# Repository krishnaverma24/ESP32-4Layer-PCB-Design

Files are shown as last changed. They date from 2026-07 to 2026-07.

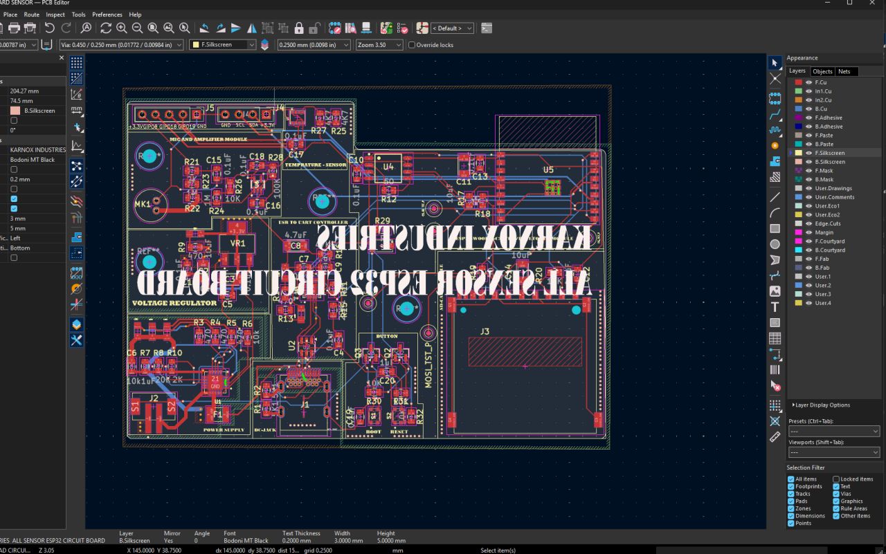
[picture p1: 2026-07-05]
1781695710935.jpg

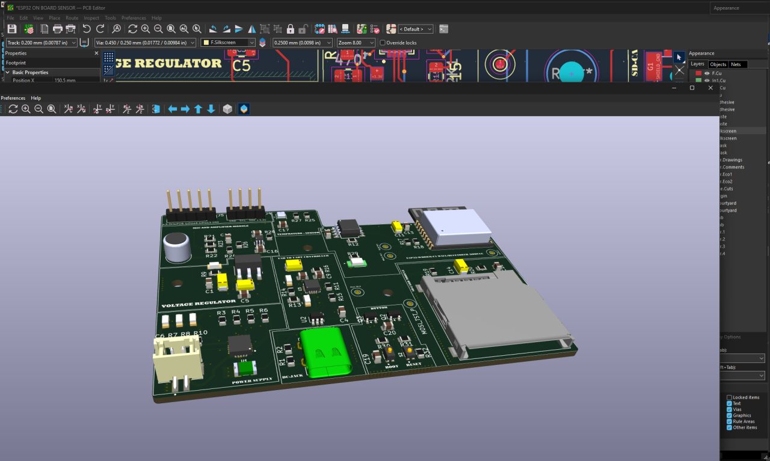
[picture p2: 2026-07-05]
1781695710932.jpg

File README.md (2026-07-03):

# ESP32 All-Sensor Board (4-Layer PCB Design)

## 📖 Overview
This repository contains the design files for a custom 4-layer PCB integrating the ESP32 microcontroller with multiple sensors and supporting circuits.  
The board is designed as a compact all-in-one sensor platform for IoT and embedded system experiments. It includes sensor interfaces, amplifier circuits, and a regulated power section, making it suitable for real-world prototyping and academic projects.

---

## ⚙️ Features
- **ESP32 Microcontroller**
  - Dual-core processor with Wi-Fi + Bluetooth
  - GPIO breakout pins for external modules
- **Integrated Sensors**
  - BMP90 sensor for pressure and temperature measurement
  - Humidity sensor interface for environmental monitoring
- **Amplifier System**
  - Signal conditioning stage for sensor outputs
  - Designed for clean analog-to-digital conversion
- **Power Section**
  - LDO-based regulation for 3.3V and 5V rails
  - Separate copper planes for power and ground
  - Decoupling capacitors for noise reduction
- **PCB Design**
  - 4-layer stack-up for optimized routing
  - Dedicated copper planes for stability
  - Compact layout with clear separation of analog and digital sections

---

## 📂 Repository Contents
- **/schematics** → Circuit schematic files (`.sch`, `.pdf`)
- **/pcb_layout** → PCB design files (`.kicad_pcb`, EasyEDA exports)
- **/gerber** → Gerber files for fabrication
- **/images** → PCB screenshots (top layer, bottom layer, 3D view)
- **README.md** → Project description and usage details

---

## 🖼️ PCB Views
Top Layer
Bottom Layer
3D View

---

## 🚀 Tools Used
- **EasyEDA** → schematic & PCB design
- **KiCad** → verification and cross-checking
- **Standard PCB workflow** → Gerber export for manufacturing

---

## 🎯 Applications
- IoT sensor fusion projects
- Environmental monitoring (temperature, humidity, pressure)
- Embedded system prototyping with ESP32
- Signal conditioning experiments with amplifier circuits
- Academic learning for PCB design and hardware integration

---

## 🛠 How to Use
1. Clone this repository  
2. Open schematic files in EasyEDA/KiCad  
3. Review PCB layout and modify if needed  
4. Use Gerber files for fabrication  
5. Assemble components and test sensor outputs with ESP32 firmware  

---

## 📌 Future Improvements
- Add more sensors (gas, accelerometer, gyroscope)  
- Improve amplifier stage for higher accuracy  
- Add USB-C power input and charging circuit  
- Integrate OLED display for real-time sensor data  

---

## 📜 License
This project is licensed under the **MIT License** – feel free to use, modify, and share with proper credit.

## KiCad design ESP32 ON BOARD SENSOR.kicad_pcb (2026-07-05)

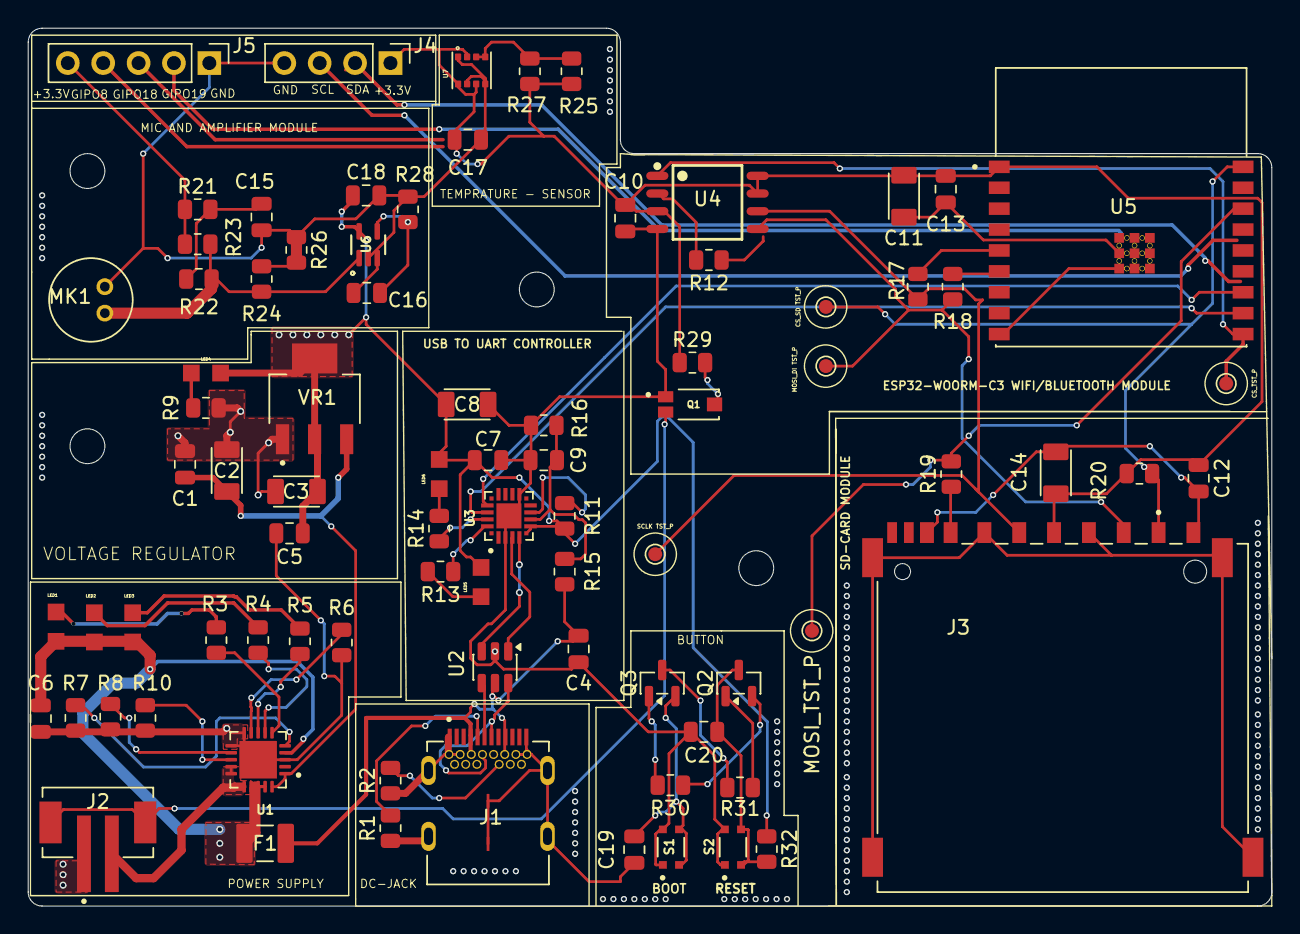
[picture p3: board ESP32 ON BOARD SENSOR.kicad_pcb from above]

Board: 4 copper layers, 89.2 x 63.0 mm, 83 parts (0 on the bottom side), 52 nets.

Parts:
C1: 0,1uF; C_0805_2012Metric
C2, C3, C13, C14: 10uF; RESC3216X125N
C4, C5, C7, C10, C11, C12, C15, C16, C17, C18, C19: 0.1uF; C_0805_2012Metric
C6, C9, C20: 1uF; C_0805_2012Metric
C8: 4.7uF; RESC3216X125N
CS_TST_P: Test CS; TestPoint_Pad_D1.0mm
F1: 0ZCH0110AF2E; FUSC3225X100N
J1: SS-52400-003; BELFUSE_SS-52400-003
J2: B2B-PH-SM4-TB; JST_B2B-PH-SM4-TB
J3: GSD090012SEU; AMPHENOL_GSD090012SEU
J4: Conn_01x04_Pin; PinHeader_1x04_P2.54mm_Vertical
J5: Conn_01x05_Pin; PinHeader_1x05_P2.54mm_Vertical
LED1, LED2, LED3, LED4, LED5, LED6: LTST-C170KRKT; DIOC200X125X110
MK1: CMC-5042PF-AC; CUI_CMC-5042PF-AC
MOSI_TST_P: Test MOSI_DO; TestPoint_Pad_D1.0mm
Q1: TEMT6000X01; TRANS_TEMT6000X01
Q2, Q3: BC817; SOT-23
R1, R2: 5K1; R_0805_2012Metric
R3, R4, R5, R9, R13, R14: 470; R_0805_2012Metric
R6, R7: 10k; R_0805_2012Metric
R8: 20K; R_0805_2012Metric
R10, R21, R22: 2K; R_0805_2012Metric
R11: 1K; R_0805_2012Metric
R12, R17, R18, R19: 50; R_0805_2012Metric
R15: 22K1; R_0805_2012Metric
R16: 47K5; R_0805_2012Metric
R20, R26, R30, R31, R32: 10K; R_0805_2012Metric
R23, R24: 1M; R_0805_2012Metric
R25, R27: 4K7; R_0805_2012Metric
R28: 100K; R_0805_2012Metric
R29: R; R_0805_2012Metric
S1: BOOT; SW_USLPT2819DT2TR
S2: RESET; SW_USLPT2819DT2TR
TP1: Test MOSI_DI; TestPoint_Pad_D1.0mm
TP3: Test SCLK; TestPoint_Pad_D1.0mm
TP4: Test CS_SD; TestPoint_Pad_D1.0mm
U1: MCP73871-2CAI_ML; QFN50P400X400X100-21N
U2: USBLC6-2SC6; SOT-23-6
U3: CP2102N-A02-GQFN20R; SILABS_CP2102N-A02-GQFN20R
U4: W25Q32JVSSIQ; SOIC127P790X216-8N
U5: ESP32-C3-WROOM-02-H4; MODULE_ESP32-C3-WROOM-02-H4
U6: MAX4466EXK; SOT65P210X110-5N
U7: BME280; PSON65P250X250X100-8N
VR1: LM1117MPX-3.3; VREG_LM1117MPX-3.3

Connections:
+3.3V: C3.1, C5.1, C7.1, C8.2, C10.1, C11.1, C12.1, C13.1, C14.1, C17.1, C18.1, J3.4 (VDD1), J4.1, J5.5, LED4.+, LED5.+, LED6.+, R11.1, R20.1, R21.1, R23.1, R25.1, R27.1, R29.1, R32.1, U3.6 (VDD), U3.7 (VREGIN), U4.3 (~WP(IO2)), U4.7 (~HOLD/~RESET(IO3)), U4.8 (VCC), U5.1 (3V3), U6.5 (VCC), U7.2 (CSB), U7.6 (VDDIO), U7.8 (VDD), VR1.2 (VOUT_2), VR1.4 (VOUT_4)
+5V: C1.1, C2.1, U1.1 (OUT), U1.20 (OUT), VR1.3 (VIN)
/+5V_USB: C6.2, F1.1, LED1.+, LED2.+, LED3.+, U1.2 (VPCC), U1.4 (PROG2), U1.17 (CE), U1.18 (IN), U1.19 (IN)
/CHARGED: R5.1, U1.8 (STAT1/~LBO)
/CHARGING: LED1.-, R3.2
/CHARGING_POWER_GOOD: R4.1, U1.7 (STAT2)
/ESP32-C3-02/CD_SD: J3.1 (CD/DAT3), R20.2, TP4.1 (1_1), U5.18 (IO0)
/ESP32-C3-02/CS: CS_TST_P.1 (1_1), U4.1 (~CS), U5.10 (IO10)
/ESP32-C3-02/MISO_DO: MOSI_TST_P.1 (1_1), R19.2, U5.16 (IO2)
/ESP32-C3-02/MOSI_DI: J3.2 (CMD), R18.2, TP1.1 (1_1), U4.5 (DI(IO0))
/ESP32-C3-02/RX_TX: U3.17 (RXD), U5.12 (TXD)
/ESP32-C3-02/SCLK: J3.5 (CLK), R17.1, TP3.1 (1_1), U4.6 (CLK)
/ESP32-C3-02/SENSORS/MIC_OUT: C16.2, R28.2, U6.4 (OUT)
/ESP32-C3-02/SENSORS/PHOTO_C: Q1.3, R29.2
/ESP32-C3-02/SENSORS/SCL: R25.2, R27.2, U7.3 (SDI), U7.4 (SCK)
/ESP32-C3-02/TX_RX: U3.18 (TXD), U5.11 (RXD)
/ESP32-C3-02/USB_D+: U2.3 (I/O2), U3.5 (D-)
/ESP32-C3-02/USB_D-: U2.1 (I/O1), U3.4 (D+)
/ESP32-C3-02/USER_INTERFACE/BOOT: C19.1, Q3.2 (E), S1.3, S1.4
/ESP32-C3-02/USER_INTERFACE/DTR: Q3.3 (C), R31.1
/ESP32-C3-02/USER_INTERFACE/EN: C20.1, Q2.3 (C), R32.2, S2.3, S2.4
/ESP32-C3-02/USER_INTERFACE/RTS: Q2.2 (E), R30.1
/USB_DN: J1.A7 (DN1), J1.B7 (DN2), U2.6 (I/O1)
/USB_DP: J1.A6 (DP1), J1.B6 (DP2), U2.4 (I/O2)
/VBAT: J2.2, U1.14 (VBAT), U1.15 (VBAT), U1.16 (VBAT_SENSE)
/VBUS: C4.1, F1.2, J1.A4 (VBUSA1), J1.A9 (VBUSA2), J1.B4 (VBUSB1), J1.B9 (VBUSB2), R15.1, U2.5 (VBUS)
GND: C1.2, C2.2, C3.2, C4.2, C5.2, C6.1, C7.2, C8.1, C9.2, C10.2, C11.2, C12.2, C13.2, C14.2, C15.1, C16.1, C17.2, C18.2, C19.2, C20.2, J1.A1 (GNDA1), J1.A12 (GNDA2), J1.B1 (GNDB1), J1.B12 (GNDB2), J1.G1 (GND/SHIELD), J1.G2 (GND/SHIELD), J1.G3 (GND/SHIELD), J1.G4 (GND/SHIELD), J1.S1 (GND/SHIELD), J1.S2 (GND/SHIELD), J1.S3 (GND/SHIELD), J1.S4 (GND/SHIELD), J2.1, J3.8 (DAT1), J3.9 (DAT2), J4.4, J5.1, MK1.GND, Q1.1, R1.1, R2.1, R6.1, R7.2, R8.2, R9.2, R10.2, R16.2, R24.2, R26.1, R26.2, R28.1, S1.1, S1.2, S2.1, S2.2, U1.3 (SEL), U1.10 (VSS), U1.11 (VSS), U1.21 (VSS), U2.2 (GND), U3.3 (GND), U3.12 (GND), U3.21 (GND), U4.4 (GND), U5.9 (GND), U5.19 (GND), U5.20 (GND), U5.21 (GND), U5.22 (GND), U5.23 (GND), U5.24 (GND), U5.25 (GND), U5.26 (GND), U5.27 (GND), U5.28 (GND), U5.29 (GND), U5.30 (GND), U5.31 (GND), U5.32 (GND), U5.33 (GND), U5.34 (GND), U5.35 (GND), U5.36 (GND), U5.37 (GND), U5.38 (GND), U5.39 (GND), U6.2 (GND), U6.3 (IN-), U7.1 (GND), U7.5 (SDO), U7.7 (GND), VR1.1 (GND)
unnamed: C15.2, R21.2, R22.1
unnamed: J1.A5 (CC1), R1.2
unnamed: J1.B5 (CC2), R2.2
unnamed: J3.7 (DAT0), R19.1
unnamed: LED2.-, R4.2
unnamed: LED3.-, R5.2
unnamed: LED4.-, R9.1
unnamed: LED5.-, R13.2
unnamed: LED6.-, R14.2
unnamed: Q2.1 (B), R31.2
unnamed: Q3.1 (B), R30.2
unnamed: R10.1, U1.13 (PROG1)
unnamed: R8.1, U1.12 (PROG3)
unnamed: R7.1, U1.5 (THERM)
unnamed: R3.1, U1.6 (~PG)
unnamed: R6.2, U1.9 (~TE)
unnamed: R13.1, U3.20 (GPIO.2/TXT)
unnamed: R14.1, U3.19 (GPIO.3/RXT)
unnamed: C9.1, R15.2, R16.1, U3.8 (VBUS)
unnamed: R11.2, U3.9 (~RST)
unnamed: R12.2, U4.2 (DO(IO1))
unnamed: R17.2, U5.5 (IO6)
unnamed: R18.1, U5.6 (IO7)
unnamed: MK1.OUT, R22.2, R23.2, R24.1, U6.1 (IN+)
SHIELD_GND: J3.3 (VSS1), J3.6 (VSS2), J3.G1 (SHIELD_GND), J3.G2 (SHIELD_GND), J3.G3 (SHIELD_GND), J3.G4 (SHIELD_GND)

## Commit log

2026-07-05 esp 32 schematic
    [ESP32 ON BOARD SENSOR.kicad_pcb, ESP32 ON BOARD SENSOR.kicad_sch, ESP32-C3-02.kicad_sch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]
2026-07-05 PCB SCHEAMTICS OR 3 D-VIEW OF PCB
    HERE I UPLOAD SOME JPG IMAGES OF REVIEW OF SCHEMATICS DIAGRAM WITH FOOTPRINTS OR COMPONNENTS THAT I ASSIGN IN EACH AND EAVERY ONE COMPENT + DIFFRENT LAYERS OF 4 LEVEL ARE WE SEE HER THEN WE SEE FULL 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
